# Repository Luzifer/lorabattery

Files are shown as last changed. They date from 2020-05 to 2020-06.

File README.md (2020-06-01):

# Luzifer / lorabattery

LoRaBattery is a monitoring device for my cars battery without all the crap the existing solutions are bringing with them plus the ability to broadcast the battery voltage through [TheThingsNetwork](https://www.thethingsnetwork.org/) using [LoRaWAN](https://lora-alliance.org/about-lorawan).

## Story

Prior I was using a Chinese BM2 device which contains a Bluetooth Low-Energy chip to make the data available. Also it is constantly on to be connected to using a smartphone with the BM2-App. This approach has a few disadvantages: It consumes a lot of energy for the device being always on, the BLE connection doesn't give a damn about who is reading the data from the device (just everyone can connect to it and read the battery history and also the first connected device hogs the connection and anyone in the vicinity can block me out). Additionally BLE is a short-range communication protocol which means I'm unable to receive measurements when my car is in its parking space and there is no chance to get the data for example into an InfluxDB.

Therefore I decided I want a device under my control which can speak to my existing infrastructure and submit the data to my [Home-Assistant](https://www.home-assistant.io/) and into my InfluxDB instance. As there are a few concrete walls between my car and my nearest WiFi access-point connecting though WiFi wasn't the solution so I searched for a transmission method more suitable for long-range communication and found LoRaWAN. The reason I chose to go though TheThingsNetwork instead of a direct connection is the possibility to receive data when I'm not near my own base-station.

## Hardware

- The base of the setup is an [Heltec ESP32 LoRa Board\*](https://amzn.to/2TY0uJT)
- Power for the board is provided using a [DC-DC Step-Down module\*](https://amzn.to/3eCMAVl)
- Voltage is measured through the boards ADC from a [Voltage Detector\*](https://amzn.to/3cnCiqP)
- Connection to the battery is established though a [CTEK Comfort Connect Cable\*](https://amzn.to/2Xklnkz)
- The box containing all of the stuff is 3D printed (see `docs` folder for source files)

(\* = Amazon Ref-Link)

## Setup



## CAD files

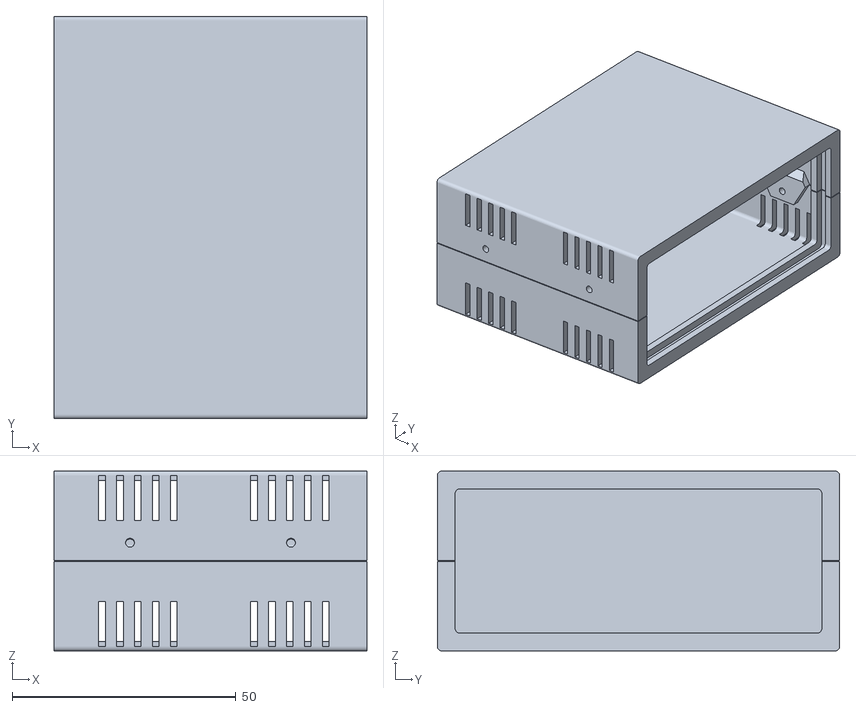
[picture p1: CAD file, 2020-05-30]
docs/box.stl
70.0 x 90.0 x 40.2

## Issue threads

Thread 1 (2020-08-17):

Power draw

probonopd, 2020-08-17:
Cool project 👍
How much power does this setup draw and how does this affect battery charge lifetime?

Luzifer, 2020-08-17:
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

It's quite hard to tell as I don't have proper measurements without measuring devices attached. My car currently has a 54Ah battery and while I needed to charge the battery every ~30d with the Chinese module attached I haven't charged it for way more than a month now (the graph above only shows ~30d because of a change in my metrics collection and a data-loss due to that).

The graph above shows the reported voltage filtered by `voltage < 13V` (above 13V is charging voltage and doesn't really show anything about the battery). The only charge the battery got were short drives with ~1.5km each. So no big drive which gave a proper charge.

Of course the short drives are impacting the discharge but in the end even without moving much the battery stays at around 11.9V so at around 40%… (Have to say that battery might not be fully okay as another device - which I don't use anymore - managed to discharge it down to a point where even the remote controlled locks didn't work anymore.)

probonopd, 2020-08-17:
Thanks for your detailed explanation, really appreciate it. Keep it up! :+1:

Closed 2020-08-17.

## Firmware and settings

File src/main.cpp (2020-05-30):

#include <cmath>

#include <TTN_esp32.h>
#include "heltec.h"

#include "config.hh"
#include "main.hh"
#include "math.hh"

TTN_esp32 ttn;

void loop() {
  // Read voltage and add as uint8 to transmission
  float voltage = readVoltage();
  uint8_t payload = (uint8_t)(int)(round(voltage * 10));

  if (ENABLE_SEND) {
    sendVoltage(payload);
  } else {
    // Sending is disabled, display value and give a moment to read
    Heltec.display->drawString(0, 22, "Current Voltage: " + String((float)payload / 10) + "V");
    Heltec.display->display();
    delay(1000);
  }

  if (voltage >= BATTERY_LOAD_VOLTAGE || DISABLE_SLEEP) {
    // We're getting power from the charger, no need to deep sleep.
    // Just wait for a moment to do the next measurement which will
    // allow us to receive a measurement shortly after car shuts down.
    delay(CHARGE_SLEEP_MS);
  } else {
    // We're running on battery and should preserve as much power
    // as possible, so we power down and ask in a few minutes again.
    esp_sleep_enable_timer_wakeup(BATTERY_SLEEP_US);
    esp_deep_sleep_start();
  }
}

float readVoltage() {
  Serial.println("Reading voltage...");

  int rawValues[MEAS_COUNT], sum;
  float rawSum = 0.0, dev = 9, mean;

  while (dev > 2) {
    sum = 0;

    for (int i = 0; i < MEAS_COUNT; i++) {
      rawValues[i] = analogRead(PIN_VOLTAGE_READ);
      sum += rawValues[i];
    }

    dev = deviation(rawValues, MEAS_COUNT);
    mean = sum / MEAS_COUNT;
  }

  int count = 0;
  for (int i = 0; i < MEAS_COUNT; i++) {
    if (rawValues[i] >= mean - dev && rawValues[i] <= mean + dev) {
      rawSum += rawValues[i];
      count++;
    }
  }

  float raw = rawSum / count;
  float vout = raw * 3.3 / 1024;
  float value = vout / (7500.0 / (30000.0 + 7500.0)) + CORRECT_DIFF;

  Serial.printf("Voltage read: %.1f %.2f\r\n", raw, value);
  return value;
}

void sendVoltage(uint8_t payload) {
  // Make sure any pending transactions are handled first
  ttn.waitForPendingTransactions();

  Heltec.display->clear();
  // Transmit voltage and display it until deep-sleep
  if (ttn.sendBytes(&payload, sizeof(payload))) {
    Heltec.display->drawString(0, 22, "Current Voltage: " + String((float)payload / 10) + "V");
  }
  Heltec.display->display();

  // Make sure our transactions is handled before going to sleep
  ttn.waitForPendingTransactions();
}

void setup() {
  Heltec.begin(true /* DisplayEnable */, false /* LoRaEnable */, true /* SerialEnable */, false /* PABOOST */, BAND /* long BAND */);

  analogReadResolution(10);

  // Initialize display for usage
  Heltec.display->init();
  Heltec.display->flipScreenVertically();
  Heltec.display->setFont(ArialMT_Plain_10);
  Heltec.display->clear();

  // Join TTN and reset counters
  Serial.println("Starting TTN");
  ttn.begin();
  ttn.join(devEui, appEui, appKey);

  // Wait for join to be completed
  Heltec.display->clear();
  Heltec.display->drawString(0, 0, "Joining TTN:");
  Heltec.display->display();
  int x = 60;
  while (!ttn.isJoined()) {
    Heltec.display->drawString(x, 0, ".");
    Heltec.display->display();
    delay(250);
    x++;
  }
  Heltec.display->clear();
  Heltec.display->drawString(0, 0, "TTN Connection online...");
  Heltec.display->display();

  // Add connection info
  Serial.println("Setup done");
  Heltec.display->clear();
  Heltec.display->drawString(0, 0, "TTN Connection online...");
}
